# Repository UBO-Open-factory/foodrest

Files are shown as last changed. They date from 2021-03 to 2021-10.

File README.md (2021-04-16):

> **Attention**
> Ce projet est en cours de développement.

# FoodRest
Code pour le Projet de poubelle connectée basée sur la solution Open Source [TOCIO](https://github.com/UBO-Open-factory/TOCIO-Back-office) permettant de collecter et afficher des données.

Ce projet présente le code Arduino pour un ESP32.

# Principe de fonctionnement du programme
Principe d’enregistrement de mesures lors de l’utilisation de la poubelle connectée.

En jaune : Les interactions avec l’utilisateur.
En Rouge, ce qu'il faut encore affiner.

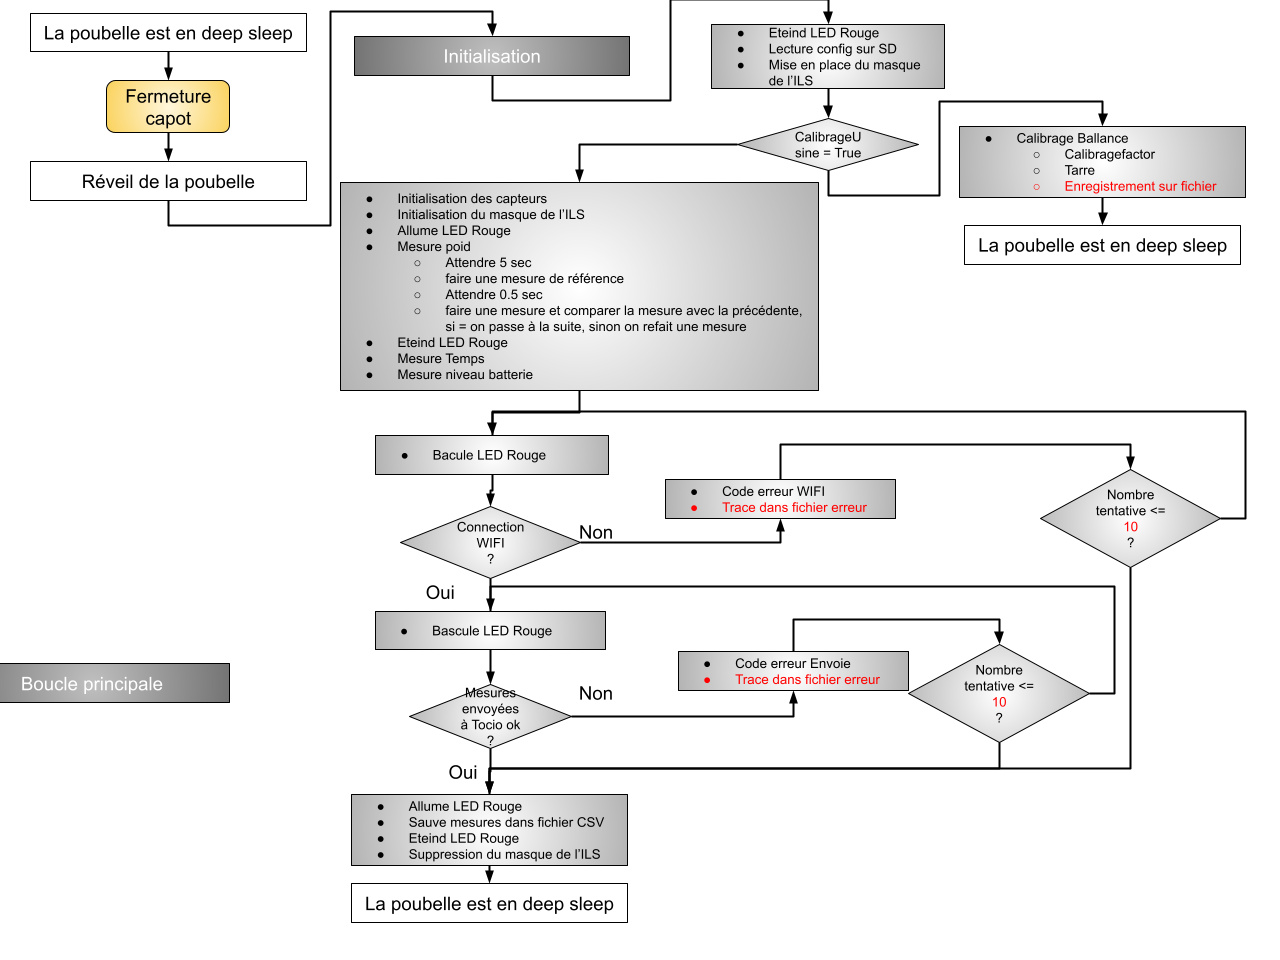
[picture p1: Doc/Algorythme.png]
Algorythme


# Installations
## Librairies Arduino utilisées
Plusieures librairies tierces sont utilisées dans le projet, pour faciliter l'intégration elles sont toutes mises 
dans le répertoire **Librairies**. 
Il suffi donc de les prendre et de les glisser dans le répertoire Arduino/librairies 
(Sous windows : C:\Users\<user>\Documents\Arduino\libraries en remplacant <user> par votre nom d'utilisateur windows.

### SDConfigFile
La librairie **SDConfigFile** est la librairie disponible sur le [dépot Git](https://github.com/bneedhamia/sdconfigfile)

Cette librairie est également disponible dans le répertoire du projet (répertoire /Librairies/SDConfigFile ).

### WiFiClientSecure
La librairie **WiFiClientSecure** est la librairie disponible sur le [dépot Git](https://github.com/espressif/arduino-esp32/tree/master/libraries/WiFiClientSecure)

Cette librairie est également disponible dans le répertoire du projet (répertoire /Librairies/WiFiClientSecure ).

### RTC
La librairie **RTC** utilisée est celle disponible sur le [dépot Git officiel Adafruit](https://github.com/adafruit/RTClib)
[Mode d'emploi](https://learn.adafruit.com/adafruit-pcf8523-real-time-clock?view=all)

Cette librairie est également disponible dans le répertoire du projet (répertoire /Librairies/RTClib ).

### Balance (HX711)
La librairie **HX711** utilisée est celle disponible sur le [dépot GIT](https://github.com/bogde/HX711)

Cette librairie est également disponible dans le répertoire du projet (répertoire /Librairies/HX711 ).

## Dépendance des librairies utilisées
Les librairies doivent être incluses les unes par rapport au autres dans l'ordre suivant :
* globalVariable.h
  * SPI.h
* GestionErreur.h
* Config.h
  * SDCard.h
	* SDConfigFile.h
		* SD.h
	* FS.h
	* SPI.h
* Tocio.h
  * WiFiClientSecure.h
    * WiFi.h
* Balance.h
  * HX711.h
* RTC.h
  * Wire.h
  * RTClib.h
  * NTPClient.h
  * WiFiUDP.h
* IDpoubelle.h
* Functions.h
  * Wire.h

# Configuration de Arduino
## Installation des cartes ESP32 dans l'IDe Arduino
Lancez l’IDE Arduino et ouvrez les préférences depuis le menu Fichier. Sur macOS, allez dans le menu Arduino puis Préférences… Cliquez sur l’icône indiquée par la flèche rouge sur la photo ci-dessous.
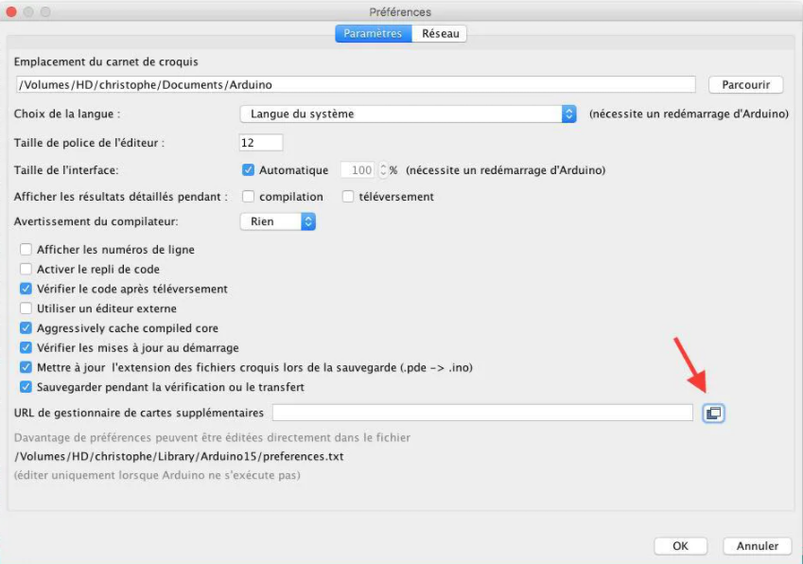
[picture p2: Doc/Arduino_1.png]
Ajout de Carte Node MCU dans l'IDE IDE

Dans le champ de saisie, collez l’adresse internet suivante puis validez
```
https://dl.espressif.com/dl/package_esp32_index.json
```
> Si vous avez déjà des définitions de cartes, vous pouvez les cumuler en les les séparant par des virgules.
> Par exemple, dans mon cas j'ai : http://arduino.esp8266.com/stable/package_esp8266com_index.json,https://dl.espressif.com/dl/package_esp32_index.json

Maintenant, allez dans le menu Outils > Type de Cartes > Gestionnaire de carte.
Dans le champ de recherche, saisissez ESP32 pour trouver les nouvelles cartes à installer. Si les cartes n’apparaissent pas, vérifiez dans les préférences que l’URL est correcte. vérifiez également la connexion Internet. Cliquer sur Installer
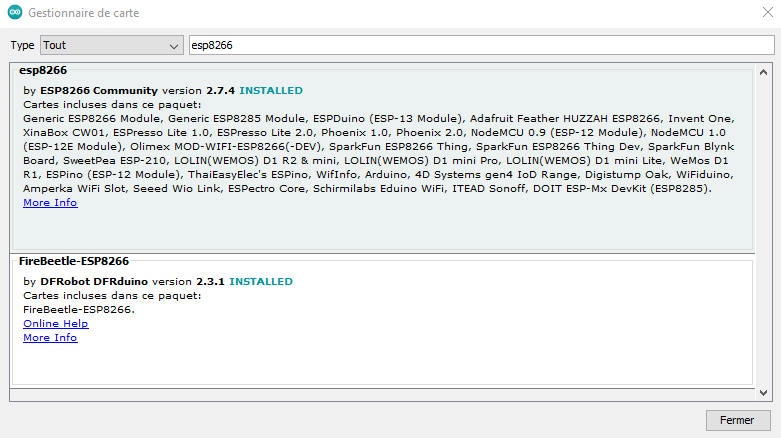
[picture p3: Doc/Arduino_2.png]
Import de la carte Node MCU dans l'IDE Import


L’installation terminée, fermez le gestionnaire de carte et ouvrez de nouveau le menu Outils > Type de Carte. 
Vous avez maintenant une nouvelle section appelée ESP32 Boards (2.7.4)

## Sélection de la carte 
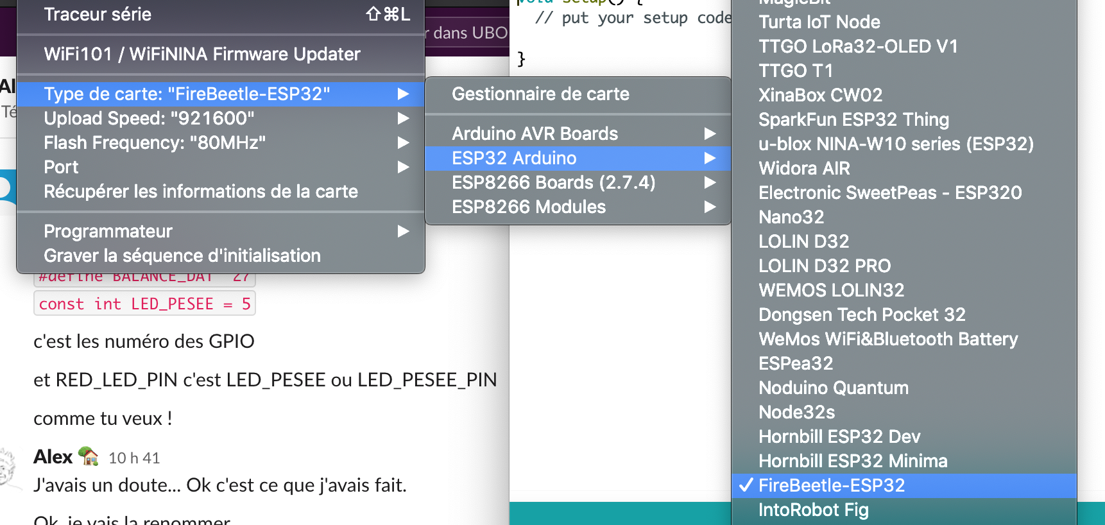
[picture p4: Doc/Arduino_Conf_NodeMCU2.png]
Utilisation de la carte Firebeetle dans Arduino


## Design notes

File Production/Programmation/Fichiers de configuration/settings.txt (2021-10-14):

// Ceci est le fichier de configuration pour l'application.

// Pour pouvoir faire la calibrage d'usine ce paramètre doit être à true (false par défault).
InitialisationUsine=true

// Pour Afficher les traces du programme dans un terminal lorsque la carte est branchée à un PC.
AfficheTraceDebug=true

// Valeur de tarage de la balance.
valeurDeTarage=0

// Calibrage de la balance (doit être une valeur entière positive ou négative).
calibrationFactor=0

// Identifiant de la poubelle tel que défini dans TOCIO.
IDPoubelle=

// Pour Afficher les traces du programme dans un terminal lorsque la carte est branchée à un PC.
poidOld=0

// Valeur initiale de tarage de la balance (** ne doit pas être modifié **).
valeurDeTarageInitial=0

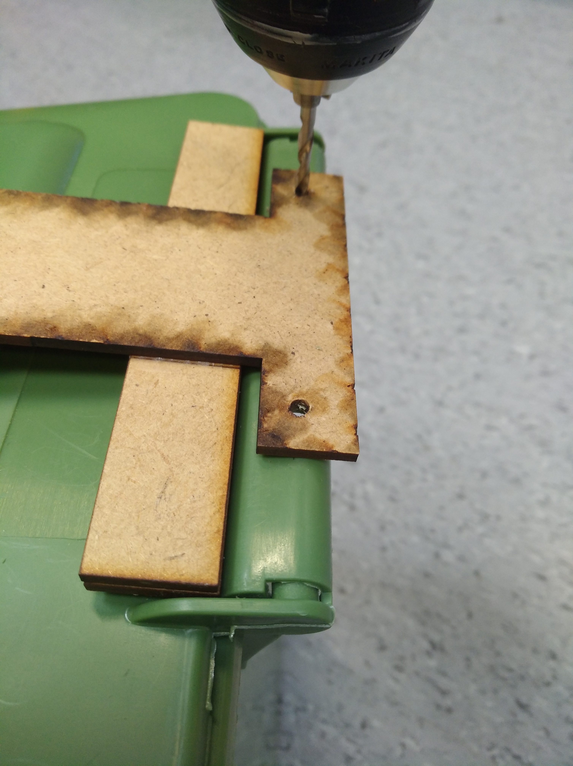
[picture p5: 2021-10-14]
Production/Mécanique/Fixation_Butée/Perçage_trous_butee_couvercle_3.jpg

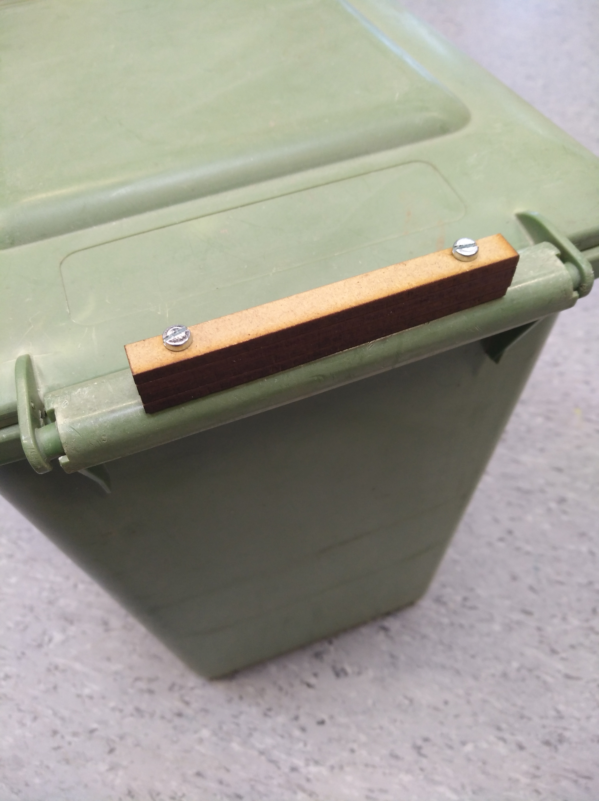
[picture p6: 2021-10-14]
Production/Mécanique/Fixation_Butée/Perçage_trous_butee_couvercle_4.jpg

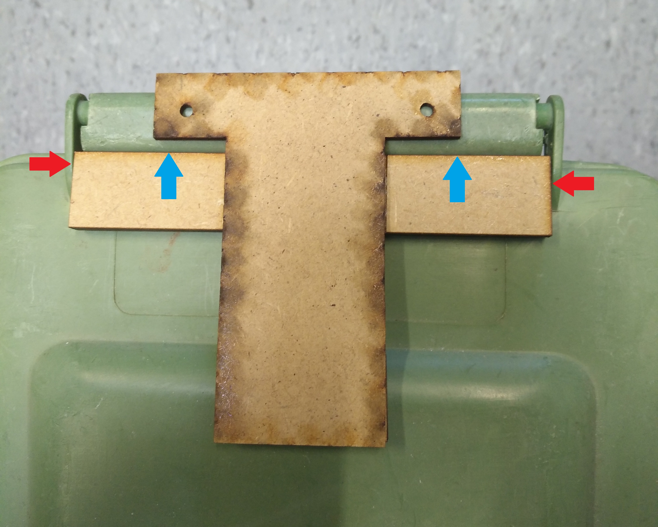
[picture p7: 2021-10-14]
Production/Mécanique/Fixation_Butée/Perçage_trous_butee_couvercle_1.jpg

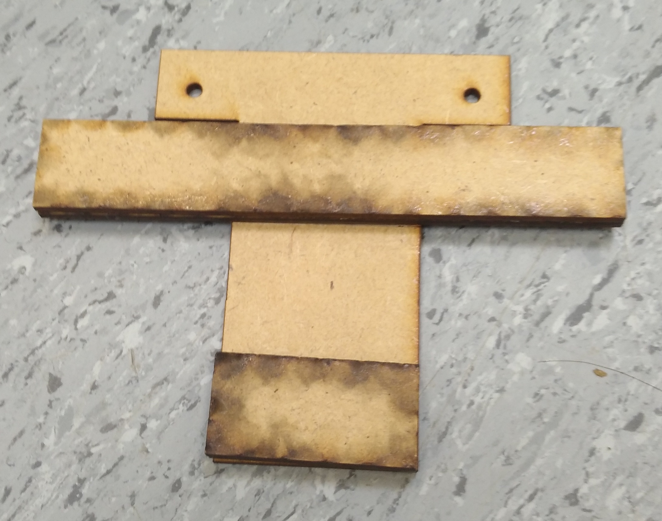
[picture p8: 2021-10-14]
Production/Mécanique/Fixation_Butée/Gabarit_percage_butee_couvercle_2.jpg

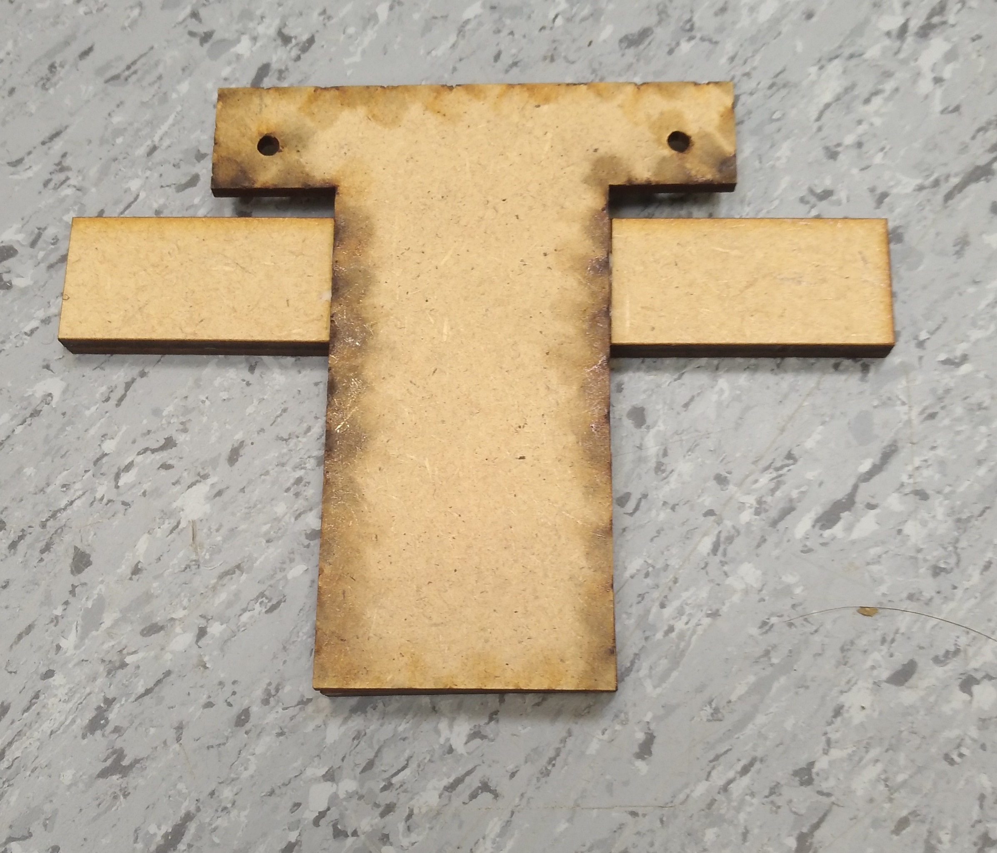
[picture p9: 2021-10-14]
Production/Mécanique/Fixation_Butée/Gabarit_percage_butee_couvercle_1.jpg

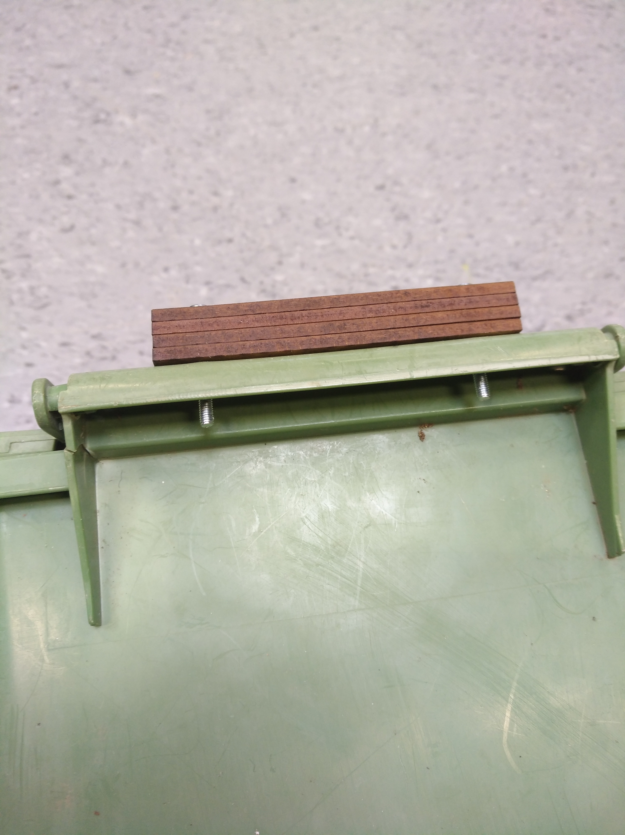
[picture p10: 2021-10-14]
Production/Mécanique/Fixation_Butée/Perçage_trous_butee_couvercle_5.jpg

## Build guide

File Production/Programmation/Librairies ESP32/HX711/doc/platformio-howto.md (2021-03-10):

# PlatformIO howto

https://platformio.org/

List installed platforms

    platformio platform list

List available boards

    platformio boards

Run specific build

    platformio ci --board=megaatmega2560 --lib="." examples/HX711_full_example

Run specific environment

    platformio run --environment lopy4

Build all environments

    platformio run

"Make clean" for all environments

    platformio run -t clean

Dump specific build environment

    platformio run --environment lopy4 --target envdump

See slot `CPPDEFINES`.

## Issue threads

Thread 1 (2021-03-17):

Mode usine

AlexP20000, 2021-03-17:
Faire un mode usine qui se déclenche lorsqu'un la variable **InitialisationUsine** (du fichier _settings.txt_) est à true.
Le mode usine permet de :
- faire le calibrage de la balance.
- mettre la RTC à l'heure.
- mettre le programme en mode DEBUG

AlexP20000, 2021-03-24:
Il manque la mise en mode debug du programme

Closed 2021-03-24.

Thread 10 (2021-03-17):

timestamp enregistré

AlexP20000, 2021-03-17:
Il semble que le timestamp enregistré ne soit pas le bon.
Chaque ligne du fichier CSV à le même depuis le début.

-> Voir du coté du formatage de la données

AlexP20000, 2021-03-18:
La pile de la RTC était pratiquement vide. Après changement, la RTC conserve sa date et son heure.
La date et l'heure sont initialisé (en mode usine uniquement) avec la date et l'heure de compilation du programme.

Closed 2021-03-24.

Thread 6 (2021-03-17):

Data sur carte SD

AlexP20000, 2021-03-17:
Ecrire les Mesures dans un fichier sur la carte SD selon le format :
IDPoubelle,timestamp,poid,niveauBatterie,PuissanceWifi,StatusEnvoieTocio

Chaque champ doit être séparé par une virgule (,)

Closed 2021-03-17.

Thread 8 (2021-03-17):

Message d'erreur sur LED

AlexP20000, 2021-03-17:
Mettre en place un clignotement de la LED en cas de message d'erreur.
Tout OK : LED éteinte
Carte SD illisible : LED clignote rapidement
En cours de pesé : LED clignote lentement
En cours de connection Wifi : LED Clignote lentement

Closed 2021-03-17.

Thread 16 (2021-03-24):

Social preview

AlexP20000, 2021-03-24:
Voir dans les settings du projet Github : Options > Social preview
Upload an image to customize your repository’s social media preview.
Images should be at least 640×320px (1280×640px for best display).

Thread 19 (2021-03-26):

Intégration du répertoire des Librairies

AlexP20000, 2021-03-26:
Il faudrait utiliser le répertoire "librairies" dans les includes des fichiers Arduino sans avoir à les copier-coller dans le répertoire de travail de l'IDE.
Attention, une fois que c'est fait, il faut modifier la documentation (le fichier README.MD)

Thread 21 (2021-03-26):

Non récupération de la date et de l'heure à l'initialisation

laurentuof, 2021-03-26:
En mode usine

.....

****************************************************
*     FOOD REST : Initialisation de l'horloge      *
****************************************************

Connection au serveur de temps...
OK.
**Il est : 01:00:05
Nous sommes le : 1/1/1970**

AlexP20000, 2021-03-31:
En fait cela fonctionne mais pas derrière un proxy, comme celui qu'il y a à l'UBO. Heureusement il y a un serveur de temps.
J'ai donc fait un questionnement sur le serveur de temps local et si ça ne fonctionne pas on va chercher le temps sur un serveur public.

Closed 2021-03-31.

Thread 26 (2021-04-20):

Perte de précision des settings

AlexP20000, 2021-04-20:
Lors de la sauvegarde des settings, il y a une conversion de float en String, voir si ça n'occasionne pas une transformation de ce qui est après la virgule en .00

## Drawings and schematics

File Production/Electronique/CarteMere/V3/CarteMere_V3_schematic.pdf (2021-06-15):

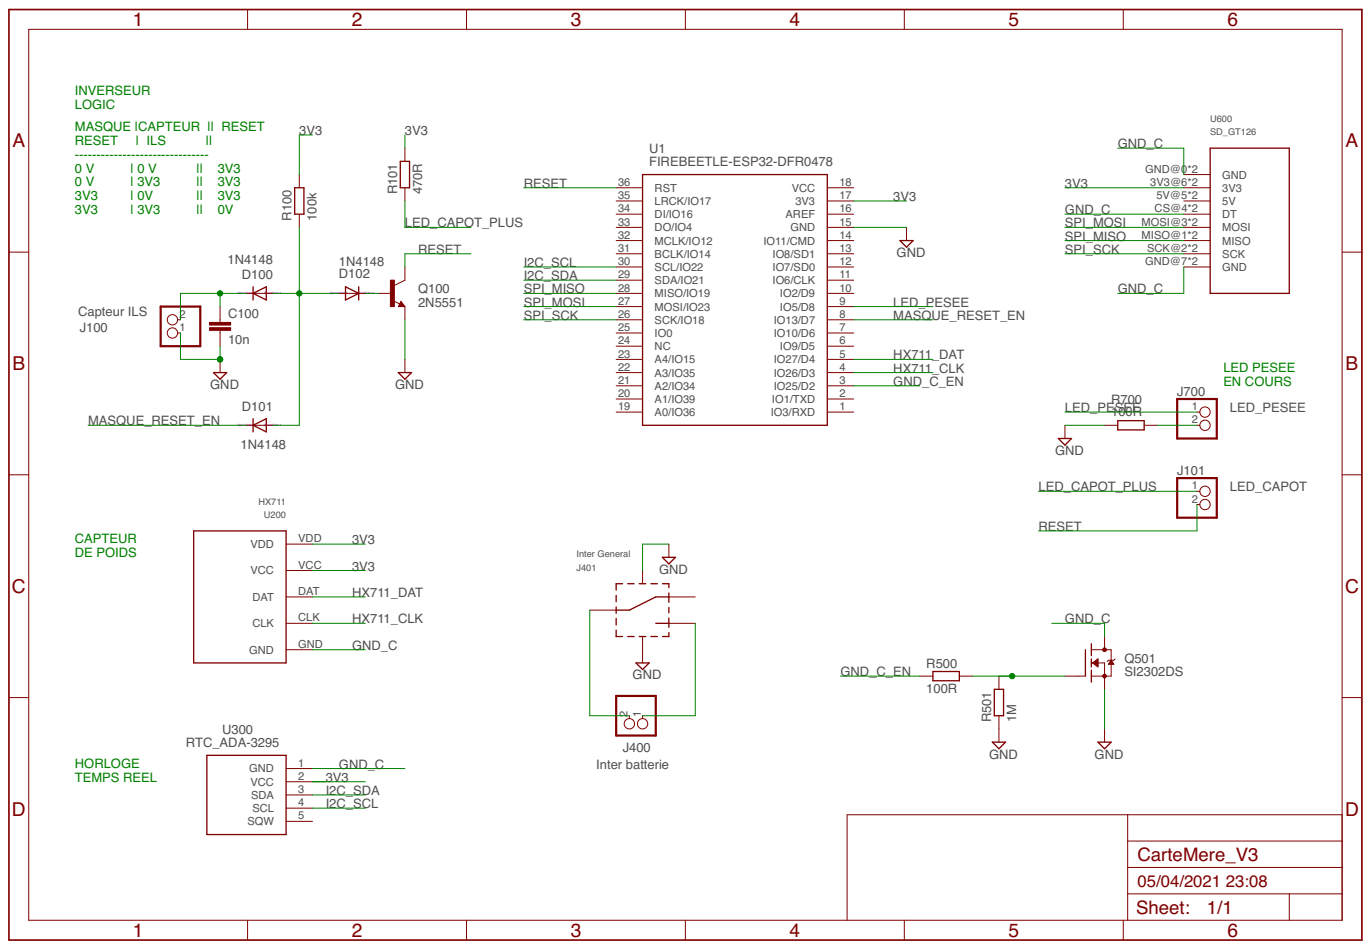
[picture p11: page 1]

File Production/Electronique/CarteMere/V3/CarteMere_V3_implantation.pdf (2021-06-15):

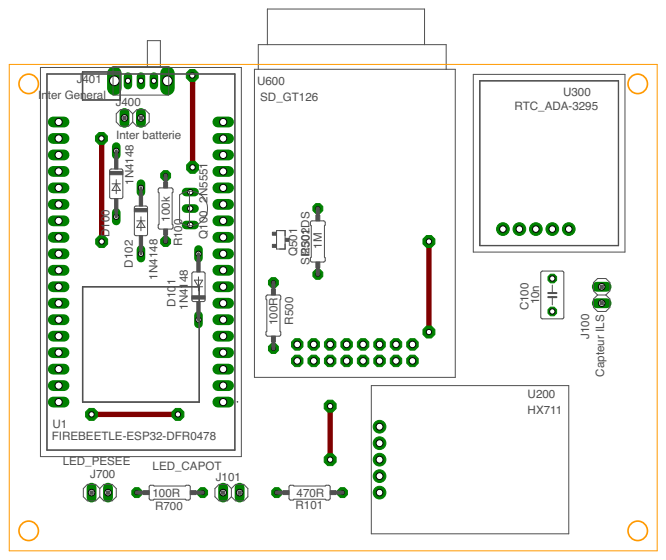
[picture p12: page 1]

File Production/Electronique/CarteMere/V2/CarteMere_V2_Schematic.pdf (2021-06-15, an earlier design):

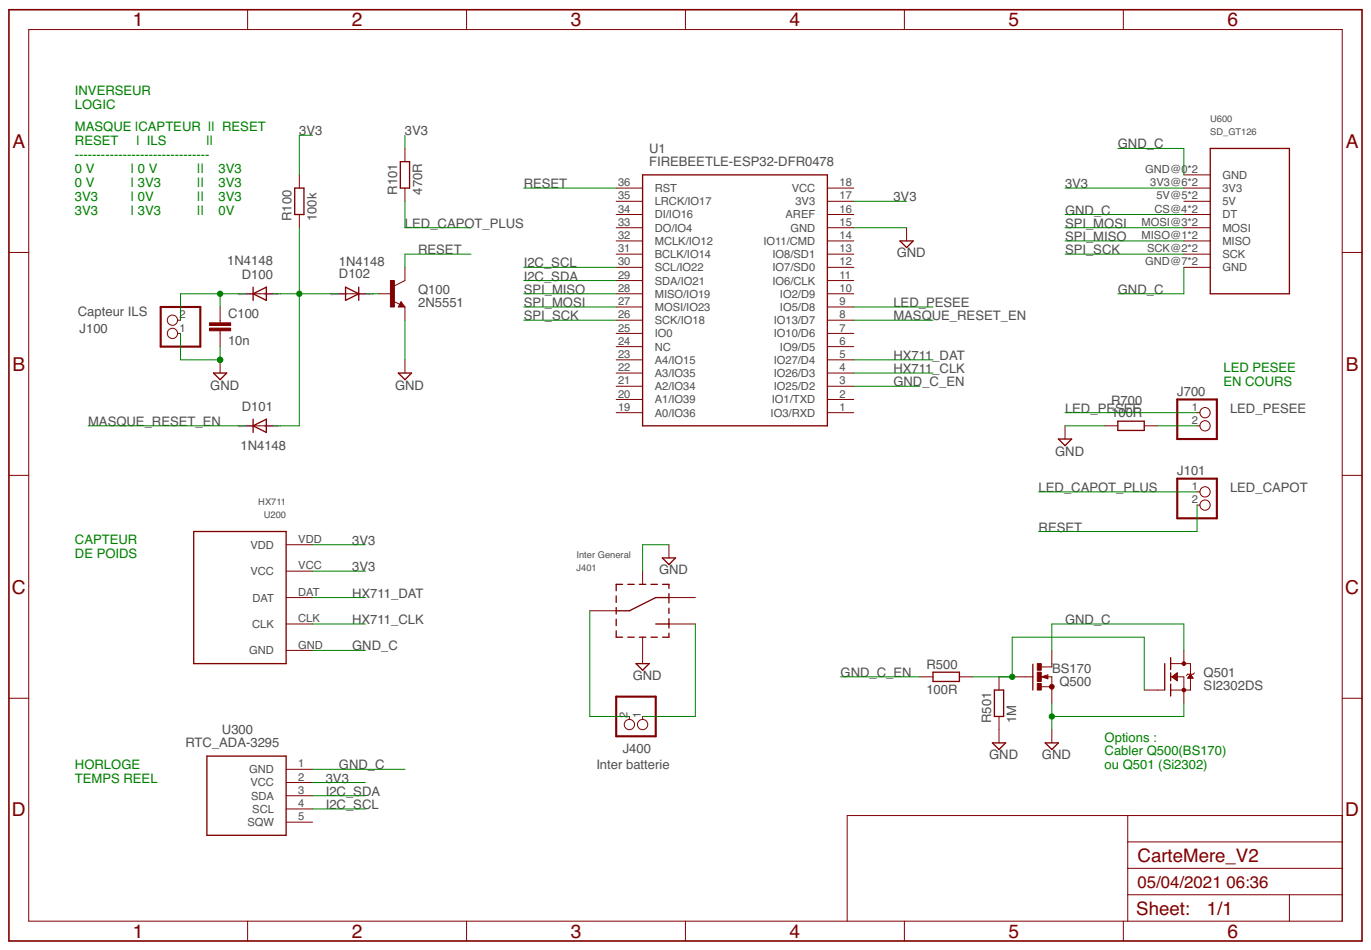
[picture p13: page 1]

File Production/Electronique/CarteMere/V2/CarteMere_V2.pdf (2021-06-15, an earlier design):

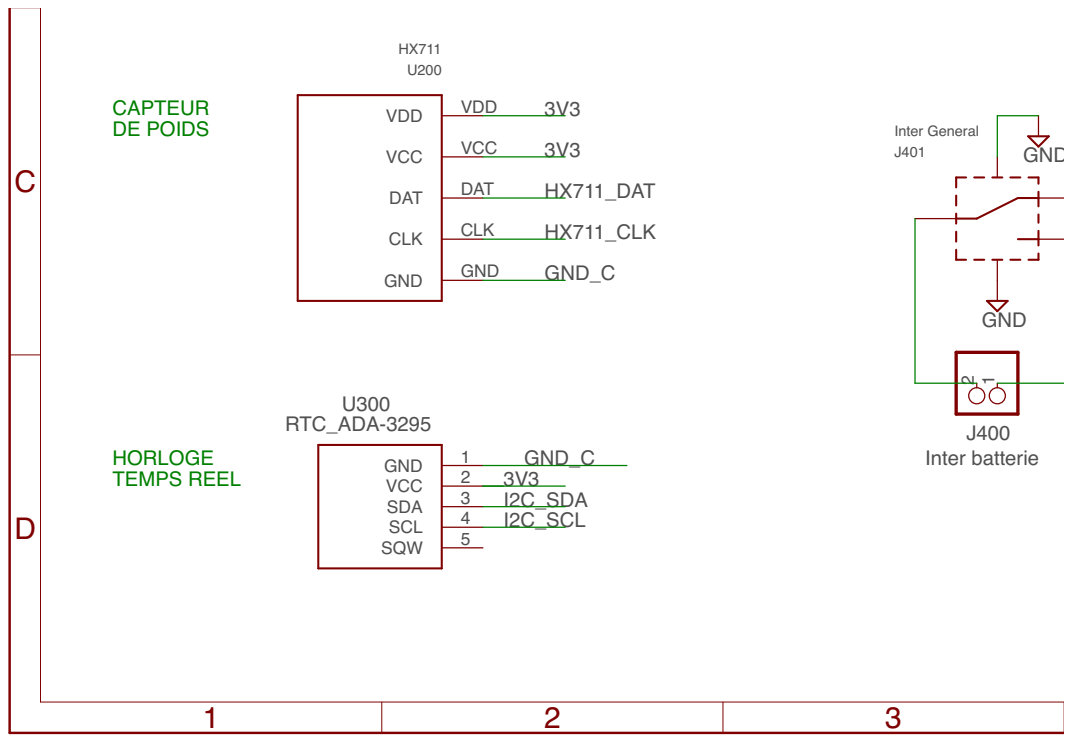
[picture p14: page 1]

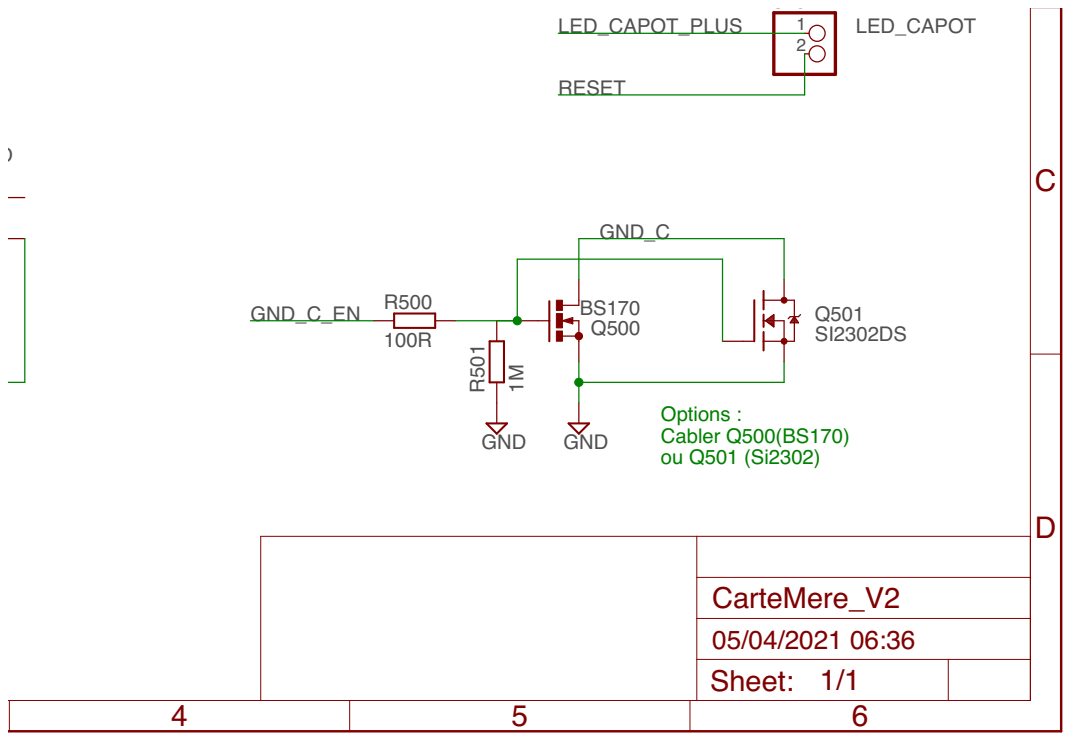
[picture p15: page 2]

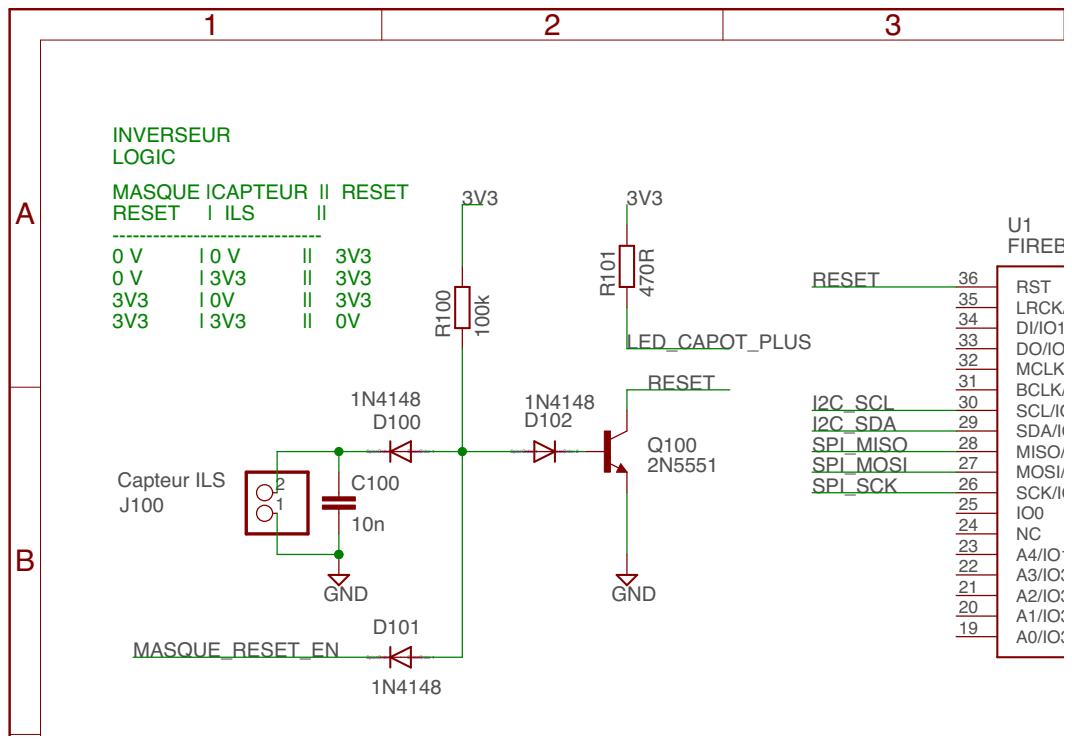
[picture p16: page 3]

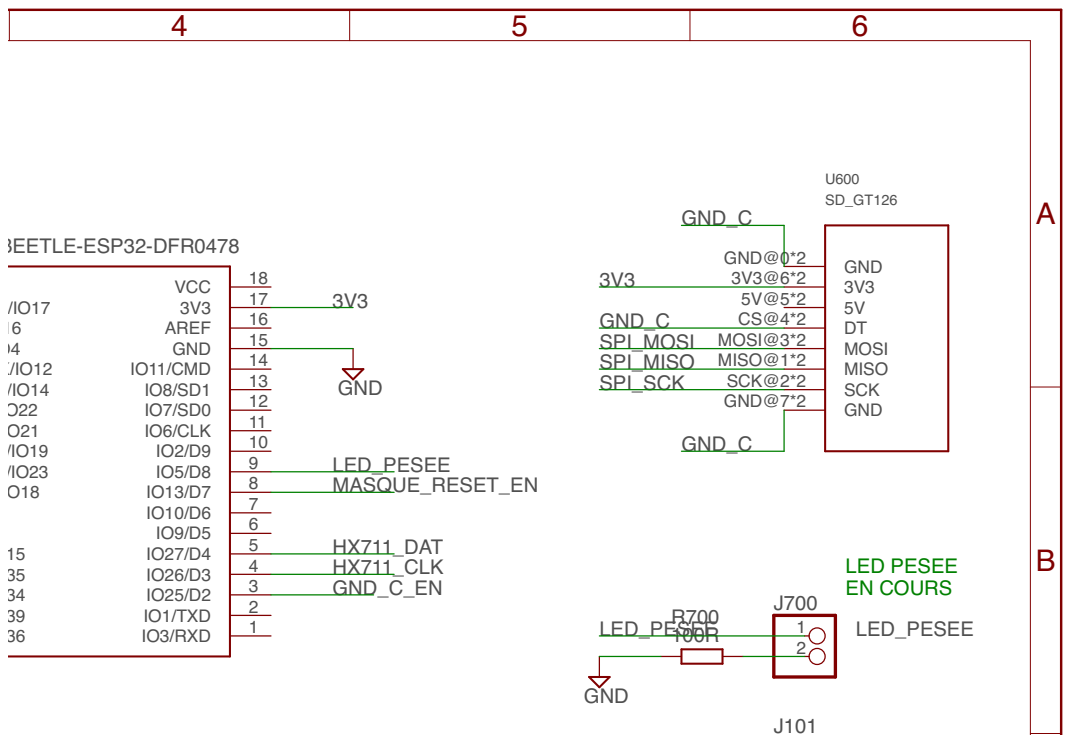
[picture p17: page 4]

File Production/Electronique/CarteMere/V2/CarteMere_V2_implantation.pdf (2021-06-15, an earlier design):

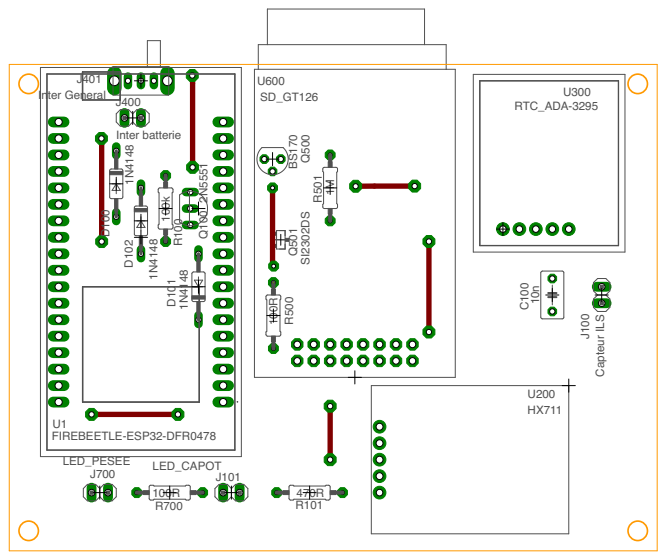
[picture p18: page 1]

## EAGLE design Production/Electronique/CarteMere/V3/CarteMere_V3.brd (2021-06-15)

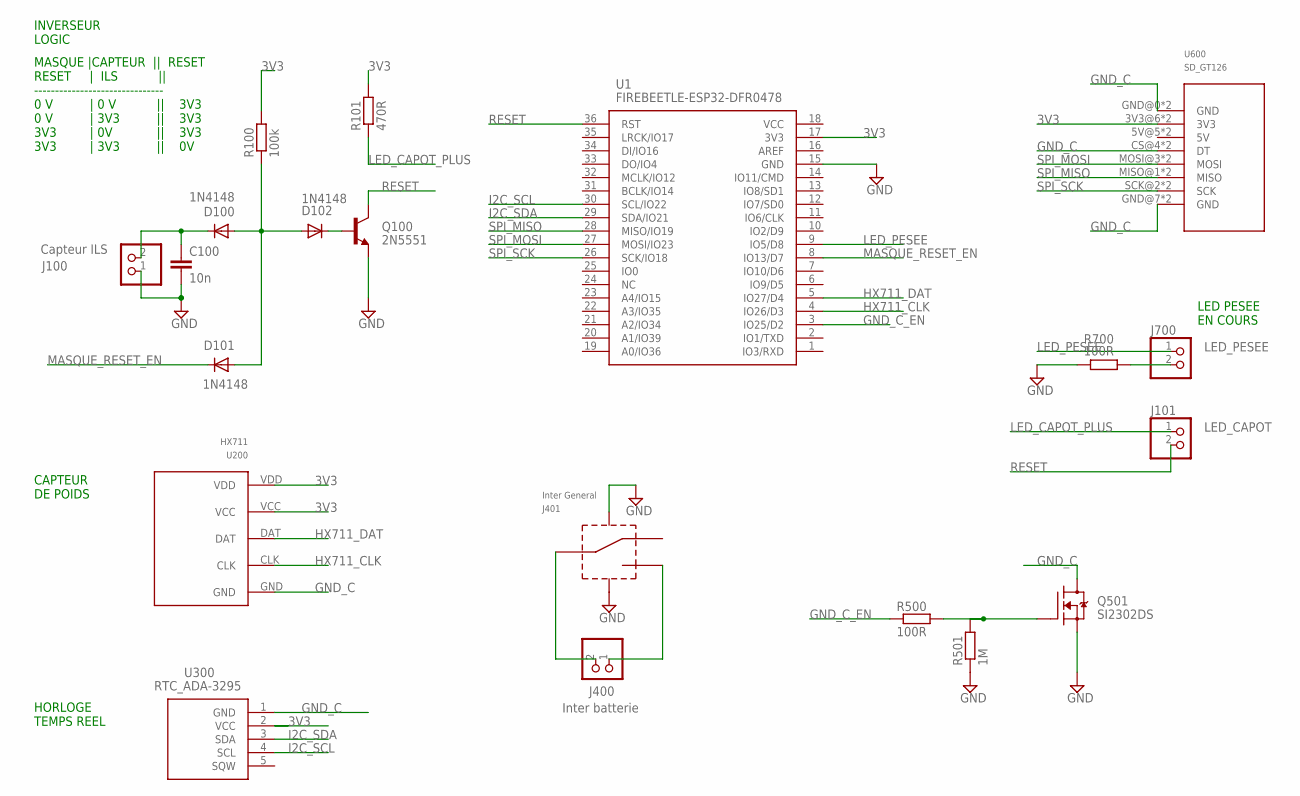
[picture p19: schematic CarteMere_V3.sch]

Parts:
C100: 10n; C050-035X075
D100, D101, D102: 1N4148; DO35-10
J100: Capteur ILS; 1X02
J101: LED_CAPOT; 1X02
J400: Inter batterie; 1X02
J401: Inter General; COMMUTATEUR_GLISSIERE_1RT_100MA
J700: LED_PESEE; 1X02
Q100: 2N5551; TO92-EBC
Q501: SI2302DS; SOT23
R100: 100k; 0207/10
R101: 470R; 0207/10
R500, R700: 100R; 0207/10
R501: 1M; 0207/10
U1: FIREBEETLE-ESP32-DFR0478; FIREBEETLE_ESP32
U200: HX711; SPARKFUN_HX711_LOAD_CELL
U300: RTC_ADA-3295; ADA3295
U600: SD_GT126

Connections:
3V3: R100.2, R101.2, U1.17 (3V3), U200.VCC, U200.VDD, U300.2 (VCC), U600.3V3@6 (3V3), U600.3V3@9 (3V3)
GND: C100.2, J100.1, J401.GNDA, J401.GNDB, Q100.E, Q501.2 (S), R501.1, R700.1, U1.15 (GND)
GND_C: Q501.3 (D), U200.GND, U300.1 (GND), U600.CS@4 (DT), U600.CS@11 (DT), U600.GND@0 (GND), U600.GND@7 (GND), U600.GND@8 (GND), U600.GND@15 (GND)
GND_C_EN: R500.1, U1.3 (IO25/D2)
HX711_CLK: U1.4 (IO26/D3), U200.CLK
HX711_DAT: U1.5 (IO27/D4), U200.DAT
I2C_SCL: U1.30 (SCL/IO22), U300.4 (SCL)
I2C_SDA: U1.29 (SDA/IO21), U300.3 (SDA)
LED_CAPOT_PLUS: J101.1, R101.1
LED_PESEE: J700.1, U1.9 (IO5/D8)
MASQUE_RESET_EN: D101.C, U1.8 (IO13/D7)
unnamed: Q501.1 (G), R500.2, R501.2
unnamed: J700.2, R700.2
unnamed: D100.A, D101.A, D102.A, R100.1
unnamed: C100.1, D100.C, J100.2
unnamed: D102.C, Q100.B
unnamed: J400.2, J401.COM
unnamed: J400.1, J401.OUTA (OUT1)
RESET: J101.2, Q100.C, U1.36 (RST)
SPI_MISO: U1.28 (MISO/IO19), U600.MISO@1 (MISO), U600.MISO@14 (MISO)
SPI_MOSI: U1.27 (MOSI/IO23), U600.MOSI@3 (MOSI), U600.MOSI@12 (MOSI)
SPI_SCK: U1.26 (SCK/IO18), U600.SCK@2 (SCK), U600.SCK@13 (SCK)

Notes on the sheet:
LED PESEE EN COURS
INVERSEUR LOGIC
CAPTEUR DE POIDS
HORLOGE TEMPS REEL
MASQUE |CAPTEUR || RESET RESET | ILS || ------------------------------- 0 V | 0 V || 3V3 0 V | 3V3 || 3V3 3V3 | 0V || 3V3 3V3 | 3V3 || 0V

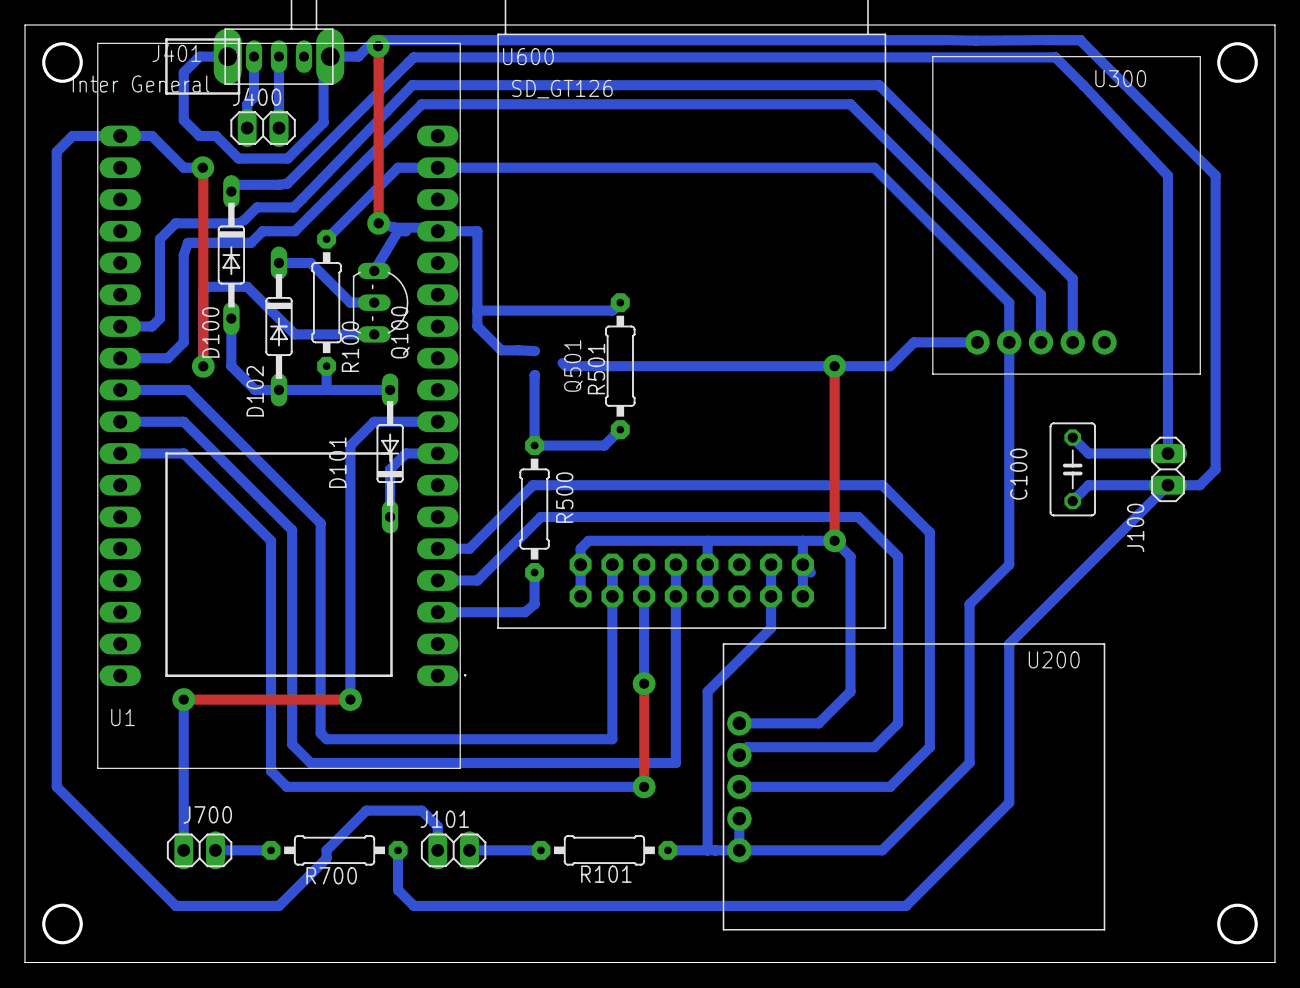
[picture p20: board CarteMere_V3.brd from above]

Board: 2 copper layers, 100.0 x 75.0 mm, 20 parts (1 on the bottom side), 22 nets.

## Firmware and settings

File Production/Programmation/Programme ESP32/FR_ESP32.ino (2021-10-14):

/*
 * 
 * Programme  : FOODREST programme principal
 * 
 * Auteurs    : Laurent MARCHAL (UOF), ALexandre PERETJATKO (UOF) Mathieu CARIOU (UOF) Tomo MUROVEC (UOF) Arthur PIGNALET (UOF)
 * 
 * Licence    : CC-BY-SA
 * 
 * Version    : 1.0
 * 
 * Date       :  14/10/2021
 */



/*
   Gestion des mesures de la poubelle connectée.
*/

// Variables globales
#include "globalVariable.h"


// Librairie de gestion des erreurs
#include "GestionErreur.h"

// Librairies pour la lecture de la configuration
#include "Config.h"

// Librairies pour le fonctionnement avec le Back office de TOCIO
#include "Tocio.h"

// Librairie de gestion de la balance
#include "balance.h"

// Librairie de gestion de la balance
#include "RTC.h"

// Librairie de gestion de la saisie de l'ID de la balance
#include "IDpoubelle.h"

// Librairies contenant les fonctions pour lire les mesures physiques.
#include "Functions.h"




// ************************************************************************************
void setup() {
  // initialisation de la liaison série (pour le moniteur)
  Serial.begin(115200);
  delay(200);  // attente pour l'init de la liaison serie

  // Orientation des E/S
  pinMode(LED_PESEE_PIN, OUTPUT);
  pinMode(GND_C_EN, OUTPUT);
  pinMode(MASQUE_RESET, OUTPUT);

  // Prépositionement des E/S
  digitalWrite(LED_PESEE_PIN, HIGH);    // allumage led "pesée en cours"
  digitalWrite(GND_C_EN, HIGH);         // alimentation des périphériques (RTC, balance carte SD)
  digitalWrite(MASQUE_RESET, LOW);      // interdiction du RESET lorsque le capot est ouvert

  //Initialisation du code erreur en mode normal
  code_erreur_normal = ERREUR_NO_ERREUR;

  // Initialisaiton de la balance ---------------------------------------------------------------------
  balance.begin(BALANCE_DAT, BALANCE_CLK);
  balance.power_up();


  // Initialisation de la carte SD ---------------------------------------------------------------------
  // Si on n'arrive pas à initialiser la carte SD
  if ( ! SD_initCard() ) {
    AfficheErreur("ERR (main)> Lecture carte SD impossible!");
    AfficheErreur("Veuillez insérer une carte SD et relancer le programme.");
    digitalWrite(GND_C_EN, LOW);      // coupe l'alimentation des périphériques
    code_erreur_normal = ERREUR_CARTE_SD;
    affichage_erreurs_mode_normale();

  } else {
    // Lecture de la config à partir du fichier sur la carte SD ---------------------------------------
    // ( renseigne le ssid, password, poid, IDPoubelle, etc... )
    configLocale = CONF_lectureConfigurationFromSD();
    TraceDebug("valeurDeTarage");
    TraceDebug(configLocale.valeurDeTarage);

    TraceDebug("laValeurDeTarageInitiale");
    TraceDebug(configLocale.laValeurDeTarageInitiale);


    // si un problème a été détecté sur la carte SD => erreur
    if ( code_erreur_normal == ERREUR_CARTE_SD) {
      affichage_erreurs_mode_normale();
    }



    // On fait un calibrage usine car la variable est positionnée à TRUE dans le fichier --------------
    // de settings
    if ( configLocale.InitialisationUsine ) {


      calibrageUsine();



      // Lecture des mesures ---------------------------------------------------------------------------
      // (on est en mode normal, pas de paramétrage usine à faire)
    } else {

      String Mesures = "";

      // TIMESTAMP
      String timeStamp = rtc_getTimestamp();
      Mesures.concat(timeStamp);

      // Pause de 4 sec pour attendre que la poubelle se stabilise avant de faire une mesure.
      delay(4000);

      // POIDS
      // pesée de la poubelle (valeur calculée)
      balance.set_scale(configLocale.calibrationFactor);
      // float poidNew = BALANCE_getPeseeBalance(configLocale.valeurDeTarage) + (configLocale.valeurDeTarage / configLocale.calibrationFactor);
      float poidNew = BALANCE_getPeseeBalance(configLocale.laValeurDeTarageInitiale);
      float deltaPesee = poidNew - configLocale.poidOld;
      configLocale.poidOld = poidNew;

      // supppression des cas très négatifs (lorsque l'on soulève la poubelle pendant une pesée)
      if (!(poidNew < -(BALANCE_POIDS_SAC + BALANCE_MARGE_POIDS_SAC))) {
  
        if (deltaPesee <0 && abs(poidNew+BALANCE_POIDS_SAC) < BALANCE_MARGE_POIDS_SAC) {
          deltaPesee=0;
          configLocale.poidOld = 0;
        }

        // arrondi des mesures pour supprimer les décimales
        deltaPesee = round(deltaPesee);
        float poidBrute = poidNew;
        poidBrute = round(poidBrute);
        
  
        // Formattage des poids pour TOCIO
        Mesures.concat(formatString(deltaPesee, "-5.0"));
        Mesures.concat(formatString(poidBrute, "-5.0"));
  
        // FORCE DU WIFI
        int rssi = 0; // Sera mis à jour lorsque la connection WIFI sera faite
        String retourTOCIO = "";
  
        // BATTERIE
        int niveauBatteri = niveau_battrie();
        if (niveauBatteri < SEUIL_LOW_BAT) {
          TraceDebug("code_erreur_normal = ERREUR_LOW_BAT");
          code_erreur_normal = ERREUR_LOW_BAT;
        }
        Mesures.concat(formatString(niveauBatteri, "4.0"));
  
        // Connection au WIFI ----------------------------------------------------------------------------
        // On a réussi à se connecter au WIFI
        if ( connectionWifi() ) {
  
          TraceDebug("Voila, c'est fait.");
          TraceDebug("IP : " + WiFi.localIP().toString() );
          TraceDebug("MAC address: " + WiFi.macAddress() );
  
          // Force du signal WIFI
          rssi = WiFi.RSSI();
  
          // Envoie des données vers TOCIO ------------------------------------------------------------
          retourTOCIO = sendDataInHTTPSRequest( Mesures, configLocale );
  
          if ( retourTOCIO != "ok") {
            AfficheErreur("ERR (main)> ERREUR lors de l'envoie vers TOCIO. L'erreur renvoyée est :");
            TraceDebug(retourTOCIO);
  
          } else  {
            TraceDebug("Envoie réussi");
          }
  
          // Pas de connection au Wifi --------------------------------------------------------------------
        } else {
          TraceDebug("Pas de Wifi... code_erreur_normal = ERREUR_WIFI");
          code_erreur_normal = ERREUR_WIFI;
        }
  
        // Ecriture dans le fichier CSV ----------------------------------------------------------------------
        Mesures = configLocale.IDPoubelle + "," + rtc_getDate() + "," + String(deltaPesee, 0) + "," + String(poidBrute, 0) + "," + String(niveauBatteri) + "," + String(rssi) + "," + retourTOCIO;
        SD_writeMesure(configLocale.IDPoubelle, Mesures);
        TraceDebug("Ecriture dans le fichier CSV");
        TraceDebug("Mesures: " + Mesures);
  
        // sauvegarde des settings
        // (pour mémoriser le poid mesuré et éventuellement la nouvelle valeur de tarage)
        SD_EraseSettings();
        SD_WriteSettings(configLocale);
      }
 
    }
    
  }

  
  // Sortie "propre"
  digitalWrite(MASQUE_RESET, HIGH); // autorise le RESET lorsque le capot est ouvert
  digitalWrite(GND_C_EN, LOW);      // coupe l'alimentation des périphériques
  digitalWrite(LED_PESEE_PIN, LOW); // extinction de la led "pesée en cours"
  balance.power_down();             // Put the ADC in Sleep mode

  // Affichage des erreurs
  affichage_erreurs_mode_normale();

  // Passage en deep sleep
  esp_deep_sleep_start();
}



void loop() {
}

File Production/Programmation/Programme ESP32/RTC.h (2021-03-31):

/**
   Toutes les fonctions concernant la RTC.
*/
#include <Wire.h>

// capteur RTC pcf8523
// Date and time functions using a PCF8523 RTC connected via I2C and Wire lib
#include <RTClib.h>
RTC_PCF8523 rtc;


// Define NTP Client to get time ******************************************************************************************************
#include <NTPClient.h>
#include <WiFiUdp.h>




//---------------------------------------------------------------------------------------
/**
      Mise à l'heure de la RTC.
      Si elle à été reinitilisée, on l'initialise avec le serveur de temps pool.ntp.org

           The PCF8523 can be calibrated for:
            - Aging adjustment
            - Temperature compensation
            - Accuracy tuning
     The offset mode to use, once every two hours or once every minute.
     The offset Offset value from -64 to +63. See the Application Note for calculation of offset values.
     https://www.nxp.com/docs/en/application-note/AN11247.pdf
     The deviation in parts per million can be calculated over a period of observation. Both the drift (which can be negative)
     and the observation period must be in seconds. For accuracy the variation should be observed over about 1 week.
     Note: any previous calibration should cancelled prior to any new observation period.
     Example - RTC gaining 43 seconds in 1 week

    float drift = 43; // seconds plus or minus over oservation period - set to 0 to cancel previous calibration.
    float period_sec = (7 * 86400);  // total obsevation period in seconds (86400 = seconds in 1 day:  7 days = (7 * 86400) seconds )
    float deviation_ppm = (drift / period_sec * 1000000); //  deviation in parts per million (μs)
    float drift_unit = 4.34; // use with offset mode PCF8523_TwoHours
    float drift_unit = 4.069; //For corrections every min the drift_unit is 4.069 ppm (use with offset mode PCF8523_OneMinute)
    int offset = round(deviation_ppm / drift_unit);
    rtc.calibrate(PCF8523_TwoHours, offset); // Un-comment to perform calibration once drift (seconds) and observation period (seconds) are correct
    rtc.calibrate(PCF8523_TwoHours, 0); // Un-comment to cancel previous calibration

     Serial.print("Offset is "); Serial.println(offset); // Print to control offset
*/
void rtc_setup_pcf8523() {

  // Si la RTC n'est pas trouvée
  if (! rtc.begin()) {
    AfficheErreur("ERR (setup_rtc_pcf8523)> Couldn't find RTC");
    abort();
  }

  // When time needs to be set on a new device, or after a power loss, the
  // following line sets the RTC to the date & time this sketch was compiled
  //    rtc.adjust(DateTime(F(__DATE__), F(__TIME__)));
  Serial.println("");
  Serial.println("");
  Serial.println("****************************************************");
  Serial.println("*     FOOD REST : Initialisation de l'horloge      *");
  Serial.println("****************************************************");
  Serial.println("Connection au serveur de temps...");

  // On va chercher l'heure sur le serveur de temps de L'UBO
  WiFiUDP ntpUDP;
  NTPClient timeClient(ntpUDP, "chronos.univ-brest.fr");
  timeClient.begin();
  timeClient.setTimeOffset(7200); // Heure de Paris GMT +2 (in secondes)
  timeClient.update();


  // Get a Time structure for days, month and year
  unsigned long epochTime = timeClient.getEpochTime();
  struct tm *ptm    = gmtime ((time_t *)&epochTime);
  String currentDate = String(ptm->tm_mday) + "/" + String(ptm->tm_mon + 1) + "/" + String(ptm->tm_year + 1900);

  // Si on a pas reussi a lire l'heure du serveur de temps
  if ( currentDate == "1/1/1970" ) {
    AfficheErreur("ERR (setup_rtc_pcf8523)> Impossible de lire l'heure sur le serveur chronos.univ-brest.fr, on essaie sur pool.ntp.org");
    timeClient.end();
    timeClient.setPoolServerName("pool.ntp.org");

    timeClient.begin();
    timeClient.setTimeOffset(7200); // Heure de Paris GMT +2 (in secondes)
    timeClient.update();

    epochTime = timeClient.getEpochTime();
    ptm    = gmtime ((time_t *)&epochTime);
    currentDate = String(ptm->tm_mday) + "/" + String(ptm->tm_mon + 1) + "/" + String(ptm->tm_year + 1900);
  }

  String formattedTime = timeClient.getFormattedTime();

  Serial.println("Il est : " + formattedTime);
  Serial.println("Nous sommes le : " + currentDate);

  // Mise à l'heure de la RTC
  rtc.adjust(DateTime(timeClient.getEpochTime()));
  rtc.start();
}




//---------------------------------------------------------------------------------------
/**
   Renvoie le timestamp actuel sous forme de chaine de 10 caractères.
   librairie adafruit RTClib
*/
String rtc_getTimestamp() {
  rtc.begin();
  rtc.start();

  DateTime now = rtc.now();
  /*
    Serial.print(now.year(), DEC);
    Serial.print('/');
    Serial.print(now.month(), DEC);
    Serial.print('/');
    Serial.print(now.day(), DEC);
    Serial.print(" (");
    //Serial.print(daysOfTheWeek[now.dayOfTheWeek()]);
    Serial.print(") ");
    Serial.print(now.hour(), DEC);
    Serial.print(':');
    Serial.print(now.minute(), DEC);
    Serial.print(':');
    Serial.print(now.second(), DEC);
    Serial.println();
    Serial.print(" since midnight 1/1/1970 = ");
    Serial.print(now.unixtime());
    Serial.print("s = ");
    Serial.print(now.unixtime() / 86400L);
    Serial.println("d");
    Serial.println();
  */
  return String(now.unixtime());
}


//---------------------------------------------------------------------------------------
/**
   Renvoie la date et l'heure sous forme de chaine de caractères.
   @return integer
   librairie adafruit RTClib
*/
String rtc_getDate() {
  rtc.begin();
  rtc.start();

  DateTime now = rtc.now();
  char jour[3]; sprintf(jour, "%02i", now.day());
  char mois[3]; sprintf(mois, "%02i", now.month());
  String date = String(jour) + "-" + String(mois) + "-" + String(now.year() );


  char hour[3]; sprintf(hour, "%02i", now.hour());
  char minute[3]; sprintf(minute, "%02i", now.minute());
  char second[3]; sprintf(second, "%02i", now.second());
  String heure = String(hour) + ":" + String(minute) + ":" + String(second);

  return date + " " + heure;
}

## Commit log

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2021-03-08 suppression de variable
    !attention fonction :sendDataInHTTPSRequest(String data)
    non fonctionnel
2021-03-09 Factorisation du code dans les fichiers de fonctions
2021-03-09 complément fonction + ajout fonction + commentary
    - ajout du pin maping des indicateur visuel + capteur CZL635_20
    - complement fonction CZL635_20 capteur de poid
    - complement fonction RTC en cours
    - ajout lien preference carte firebeetle esp8266
2021-03-09 suppression bout de code RTC inutile + procedure de test
2021-03-09 Mise en place de la structure du main
2021-03-10 Utilisation du fichier de paramétrage pour la calibration
2021-03-10 Nettoyage de code et commentaires
2021-03-10 Correction erreur de typo
2021-03-10 Lecture de la configuration à partir de la (fake) carte SD
    Pour l'instant on utilise une fonction avec les paramètres écrit en dur
2021-03-10 Algorythme d'envoie des mesures.
2021-03-10 Documentation des librairies utilisées
2021-03-12 Modification de l'URL pour le BO de TOCIO
    On utilise maintenant le BO spécifique au projet Food Rest
2021-03-12 tentative de deggu
    pb au niveau de fonction -> niveau_battrie
    apres le "debug f2"
2021-03-12 Création d'un fichier de configuration type
    Ce fichier sera à mettre sur la carte SD
    [configuration.txt]
2021-03-12 Mise en place de la fonction de calibrage usine
2021-03-15 Formattage rapide du fichier de configuration externe
    [configuration.txt]
2021-03-15 Ajout de l'image de l'Algorythme
2021-03-15 Ajout de la légende du graphique
2021-03-15 Envoie de data dans le BO TOCIO
    La trame envoyée est bien reçue dans le BO. IL faut maintenant mettre de vrais données.
2021-03-16 Documentation sur l'installation de l'environnement de Développement
    Documentation faite pour Windows
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2021-03-16 Lecture des configurations à partir de la carte SD
    [configuration.txt]
2021-03-16 Librairie de lecture de fichier de configuration
    [example.cfg]
2021-03-17 Data sur carte SD
    Ecriture des données sur carte SD
2021-03-17 Allumage et extinction de la LED Rouge
    Mise à jour de l'algorythme pour prendre en compte l'allumage et l'extinction de la LED Rouge tout au long des mesure, envoies et sauvegarde des données.
2021-03-17 Optimisation de l'affichage des traces de debug et message erreur
2021-03-17 Clignotement LED
    La LED clignote plus ou moins rapidement en fonction de l'erreur rencontré.
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2021-03-23 Optimisation de la gestion des message de debug
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2021-03-23 Intégration de la procédure de calibration de la balance
2021-03-23 Mise à jour des dépendance des librairies utilisées
    https://github.com/UBO-Open-factory/foodrest/projects/1#card-57529780
2021-03-24 Correction de trace lors du calibrage de la balance
    [globalVariable.h]
2021-03-24 Mise à jour des dépendances de la RTC
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2021-03-24 Récupération de la sur un serveur de temps
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2021-03-24 Documentation de l'installation des cartes NODE MCU dans l'IDE Arduino
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2021-03-24 Simulation du DeepSleep
    Affichage d'un message sur le terminal Série et clignotement très lent de la LED.
2021-03-24 Passage en DeepSleep uniquement si on est pas en mode debug.
    Le mode Debug est à mettre à true/false dans le fichier de settingsd.
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2021-03-29 Saisie de l'identifiant de la poubelle lors du paramétrage usine
2021-03-29 Ajout du répertoire pour le projet avec un ESP32
2021-03-29 Mise à jour des liens sur les projets
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2021-03-31 Utilisation de la librairie FS
    Il faut donc avoir des chemin relatif dans les noms de fichiers
2021-03-31 Lecture du serveur de temps à l'intérieur de l'Université ou sinon un public
2021-03-31 Ecriture de l'entete du fichier CSV à la création de l'ID de la poubelle
2021-03-31 Lecture du résultat provenant du server TOCIO lors de l'envoie de données
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2021-03-31 mise à jour des liens sur les images
2021-04-01 Masque reset ok - deepsleep adapté à ESP32
    Masque reset ok.
    Instruction deep sleep modifiée pour s'adapter à l'ESP 32
    [FR_ESP32.ino, globalVariable.h]
2021-04-01 synchro usb/IDE
    Insertion d'un rappel visuel pour lancer la calibration (resynchro du port USB) de l'IDE
2021-04-01 Nouvelle procédure de tarage
    nouvelle procédure de tarage et de calibration
2021-04-02 Erreurs - batterie
    Gestion des erreurs OK
    Gestion batterie OK
    Affichage code erreur LED OK
2021-04-02 Amélioration tarage et pesée
    Augmentation du nb d'échantillons pour le tarage et la pesée
2021-04-05 AjoutFichierV2
    Ajout
    -Sch
    -Brd
    [CarteMere_V2.brd, CarteMere_V2.sch]
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2021-04-05 add V3
    [CarteMere_V2.brd, CarteMere_V2.sch, CarteMere_V3.brd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]
2021-04-16 Tests divers (#23)
    * Version initiale
    * Test RTC
    * mode deep sleep et conso
    * amélioration ergonomie lors du test du masque de reset
    * Version initiale du test du capteur de poids
    * Déclaration des variables globales
    * Lecture et écriture des variables
    * Initialisation des variables
    * Formatage du code
    * Nettoyage de code
    * Mesure du poids brute
    * Ecriture de la mesure brute dans le fichier CSV
    * Suppression du retour chariot lors de la saisie du l'ID de le poubelle.
    * Changement de librairie HX711 pour les pesées avec un ESP
    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
    [FR_ESP32.ino, GestionErreur.h, HX711_basic_example.ino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]
2021-04-20 Renommage de la variable de mesure de la tare initiale
2021-06-15 création architecture des dossier
    - ajout dossier "développement"
    [example.cfg]
2021-06-15 Réorganisation des dossiers
    [CarteMere_V2.brd, CarteMere_V2.sch, CarteMere_V3.brd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]
2021-10-14 Version stable
    Programmée dans toutes les poubelles de la 2ème campagne de mesures
2021-10-14 ajout du cartouche de commentaire en tête du programme principal
2021-10-14 Ajout des fichiers de configuration
    Ajout dans l'arborescence des fichiers de configurations (wifi et config)
2021-10-14 Réorganisation des répertoires
    [CarteMere_V2.brd, CarteMere_V2.sch, CarteMere_V3.brd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]
